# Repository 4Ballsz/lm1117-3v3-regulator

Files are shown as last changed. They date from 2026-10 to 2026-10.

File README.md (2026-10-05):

# LM1117 3.3 V Regulator Board

A 5 V → 3.3 V linear regulator board for loads up to 500 mA, on a 28 × 17 mm two-layer PCB. I did the schematic, part selection, layout and fabrication outputs in Altium Designer 26. It was my first PCB.

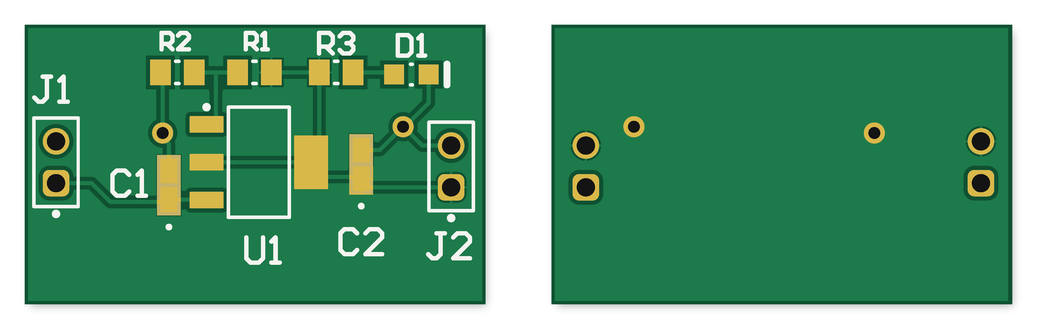
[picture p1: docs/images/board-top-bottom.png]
Top and bottom of the board, rendered from the fabrication Gerbers

<sub>Top (left) and bottom (right), rendered from the Gerber and drill files in [`fabrication/`](fabrication/).</sub>

> **Status:** design complete, DRC clean, fabrication files generated. Not yet fabricated or tested. All performance figures below are calculated, not measured.

---

## Specs

| | |
|---|---|
| Input | 5 V via J1 (2-pin 2.54 mm header) |
| Output | 3.29 V nominal, 3.19–3.41 V worst case, via J2 |
| Design load | 500 mA |
| Regulator | TI LM1117-ADJ, SOT-223 |
| Dissipation at full load | 0.85 W |
| Junction temperature | 89 °C at 25 °C ambient, 109 °C at 45 °C (limit 125 °C) |
| Board | 28 × 17 mm, 2 layers, 1 oz copper |
| Power indicator | Red LED on the 3.3 V rail, 3 mA |
| Parts | 9 components, $5.64 CAD ([BOM](bom/BOM.csv)) |

## Schematic

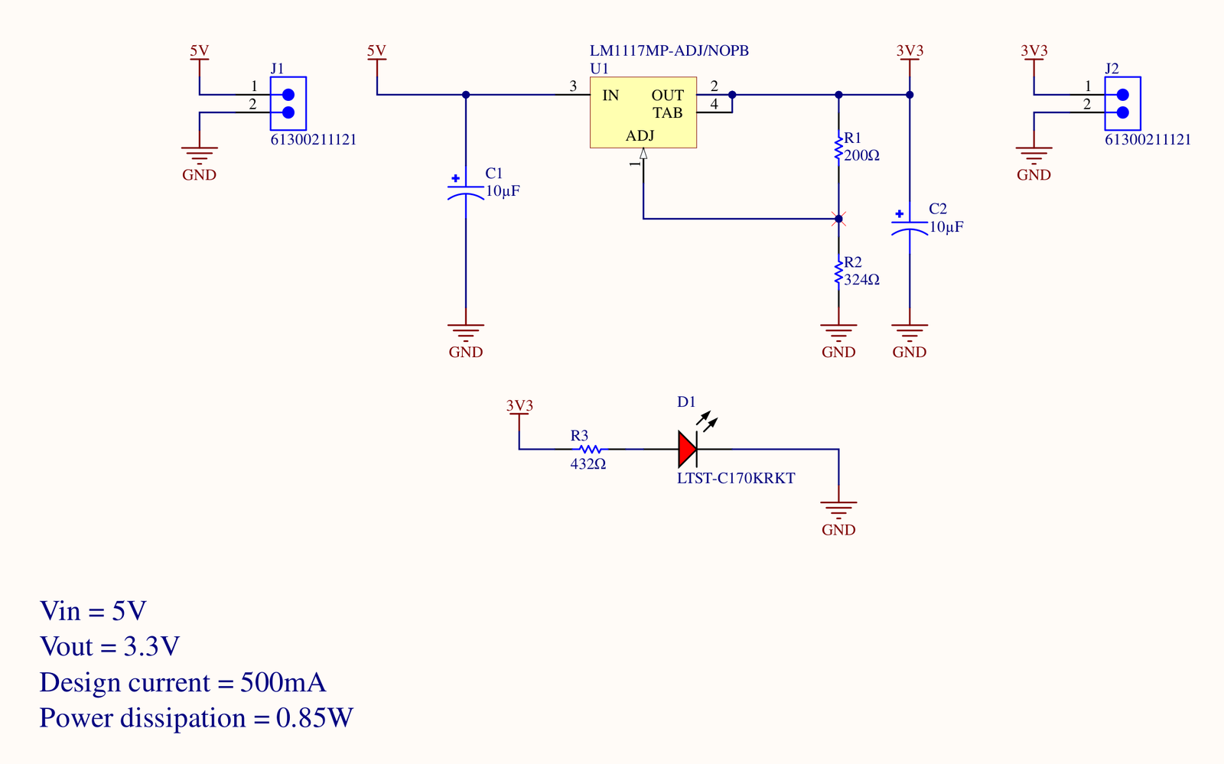
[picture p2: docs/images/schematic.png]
Schematic


- **J1** brings in 5 V and **J2** takes 3.3 V out. Pin 1 is the rail and pin 2 is ground on both. Pin 1 is the square pad.
- **R1/R2** set the output voltage through the ADJ pin.
- **C1** on the input and **C2** on the output, both tantalum.
- **D1 + R3** sit on the 3.3 V rail, so the LED shows the regulator is actually producing an output, not just that 5 V is plugged in.

Full sheet: [`docs/schematic.pdf`](docs/schematic.pdf)

---

## Key design decisions

Full working for every number is in [`docs/design-notes.md`](docs/design-notes.md).

**Output voltage: R1 = 200 Ω, R2 = 324 Ω**

    Vout = Vref × (1 + R2/R1) + Iadj × R2
         = 1.25 × (1 + 324/200) + 60 µA × 324
         = 3.275 + 0.019 = 3.294 V

- My first attempt was 1 kΩ / 1.65 kΩ. There the ADJ pin current alone added 99–198 mV (+3 % to +6 %). Dropping both by 5× cut that to 19–39 mV.
- The divider now draws 6.25 mA. That's also above the LM1117's 5 mA worst-case minimum load, so the output stays in regulation with nothing plugged into J2.
- Worst case with 1 % resistors, Vref limits and ADJ current over 0–125 °C is 3.19–3.41 V, inside a ±5 % rail (3.135–3.465 V).

**Thermal: 346 mm² copper pour on the tab**

    P  = (Vin − Vout) × I = (5 − 3.3) × 0.5 = 0.85 W
    Tj = Ta + P × θJA

- The SOT-223 tab is V_OUT, not ground (datasheet Fig. 6-1). So the heatsink pour is on the 3V3 net, not GND.
- With the bare pad (θJA = 136 °C/W) the junction would hit 141 °C at 25 °C ambient, so the pour is required.
- The built pour is 346 mm² (0.54 in²). That puts θJA at about 75 °C/W (TI Table 9-2), giving Tj = 89 °C at 25 °C and 109 °C at 45 °C.

**Output capacitor: tantalum, chosen for ESR**

- The LM1117 needs 0.3–22 Ω of ESR on the output capacitor to keep its loop stable.
- A ceramic (≈5 mΩ) or a tantalum-polymer part is below that window and could oscillate.
- Used a Kyocera AVX F921A106MPA: 10 µF, 10 V, ESR 6 Ω. The 10 V rating is 2× derating on the 5 V input, since tantalums fail short when over-voltaged.

**Trace width: 0.254 mm everywhere**

    IPC-2221 (external): I = 0.048 × ΔT^0.44 × A^0.725

- At 1 oz (1.4 mil), a 0.254 mm trace carries 0.90 A for a 10 °C rise, or rises 2.7 °C at 0.5 A.
- The minimum width for 0.5 A would be 0.11 mm.

## Layout

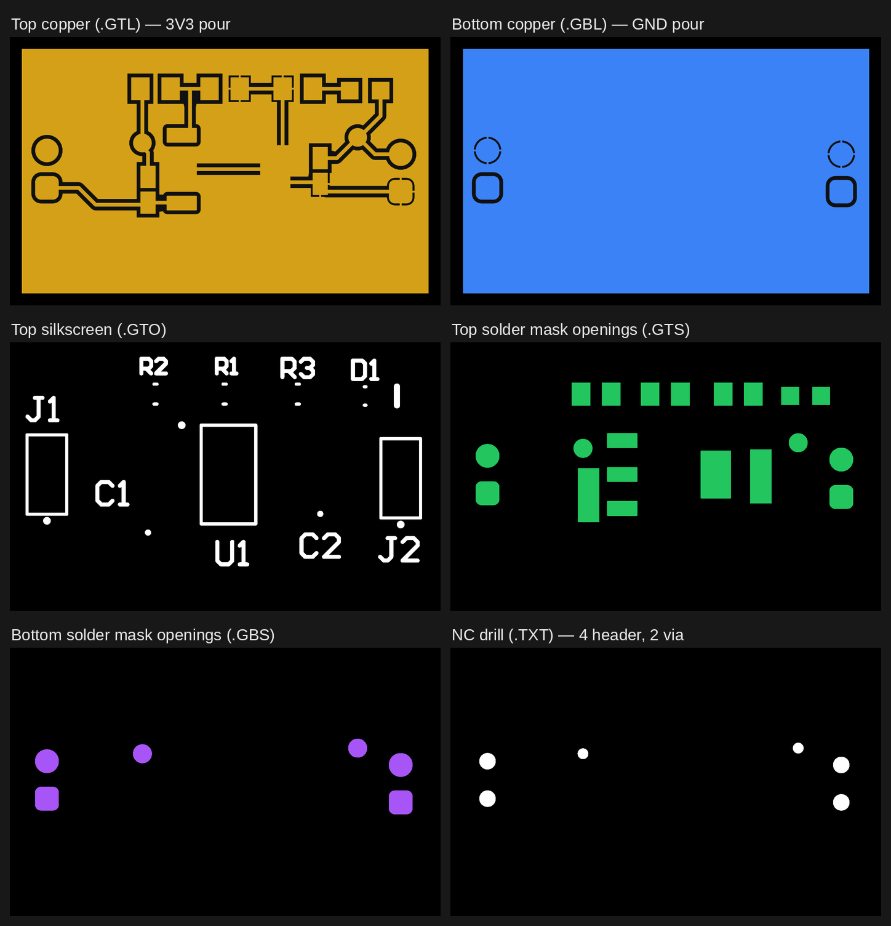
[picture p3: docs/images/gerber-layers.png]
Gerber layers


- **Top:** 3V3 pour (346 mm²) bonded to the regulator tab with a **direct connect** rule on U1. Thermal-relief spokes would choke the heat path the pour exists for. Everything else uses 4-spoke relief so it stays hand-solderable.
- **Bottom:** solid GND pour. J1/J2 ground pins are through-hole and land on it directly. The SMD ground pads on top reach it through **two 0.71 mm vias**.
- **Placement** runs input on the left to output on the right: J1 → C1 → U1 → C2 → J2. The divider and LED sit in a row along the top edge.
- **C1/C2 solder mask:** the tantalum footprint leaves only 0.24 mm between pads, under the 0.254 mm minimum mask sliver. I set +0.2 mm mask expansion on those two parts, which merges each pair of openings into one. No sliver means no violation, at the cost of no mask dam between the pads, so they need care to avoid a solder bridge.

**DRC: 0 violations, 0 warnings** ([report](docs/DRC_report.html)). The exported Gerber and drill files were also cross-checked independently: holes centred on pads, netlist, pour area, polarity. See [`docs/verification.md`](docs/verification.md).

## Bill of materials

| Ref | Part | MPN | Package | Qty | Unit (CAD) |
|---|---|---|---|---|---|
| U1 | LDO regulator, adjustable | TI LM1117MP-ADJ/NOPB | SOT-223 | 1 | 2.58 |
| C1, C2 | 10 µF 10 V tantalum, ESR 6 Ω | Kyocera AVX F921A106MPA | 0805 | 2 | 1.00 |
| R1 | 200 Ω 1 % | KOA RK73H2ATTD2000F | 0805 | 1 | 0.14 |
| R2 | 324 Ω 1 % | KOA RK73H2ATTD3240F | 0805 | 1 | 0.14 |
| R3 | 432 Ω 1 % | KOA RK73H2ATTD4320F | 0805 | 1 | 0.14 |
| D1 | Red LED | Lite-On LTST-C170KRKT | 0805 | 1 | 0.26 |
| J1, J2 | 2-pin header, 2.54 mm | Würth 61300211121 | THT | 2 | 0.19 |
| | | | | **9** | **$5.64** |

With DigiKey part numbers: [`bom/BOM.xlsx`](bom/BOM.xlsx) · [`bom/BOM.csv`](bom/BOM.csv)

## Known issues and Rev 2

- **Mechanical 1 carries a "U1" label** from the regulator footprint as well as the board outline. Use `PCB2.GM` (board profile) as the outline layer when ordering. See [`fabrication/README.md`](fabrication/README.md).
- **No pin labels on the silkscreen.** Only the square pad marks pin 1. Rev 2 should print `5V` / `GND` / `3V3` next to J1 and J2.
- **No reverse-polarity protection.** Swapping the J1 wires would reverse-bias C1. A series Schottky or P-FET would fix that at the cost of some headroom.
- **Thermal numbers come from TI's still-air test board**, not a measurement. Rev 2 would build the board and check the tab temperature at 500 mA.

## Repository layout

```
hardware/      Altium project: LM1117_Regulator.PrjPcb (open this), Sheet1.SchDoc, PCB2.PcbDoc,
               LM1117_Regulator.BomDoc (ActiveBOM), F921A106MPA/ (capacitor symbol + footprint)
fabrication/   Gerbers (RS274X, mm 4:4), NC drill, zipped fab package, fab notes
bom/           Bill of materials (.xlsx with formulas, .csv)
docs/          Schematic PDF, design notes, verification, DRC report, images
```

## Background

The requirements (5 V → 3.3 V at 500 mA, LM1117-ADJ, two layers) came from the WATonomous Humanoid electrical onboarding assignment. This repository is my own cleaned-up version of that design.

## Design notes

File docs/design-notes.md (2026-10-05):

# Design notes

Full working behind every number in the README. Datasheet references are to the TI LM1117 datasheet (SNOS412) unless stated otherwise.

---

## Datasheet values used

| What | Value | Where |
|---|---|---|
| Tab connection | **V_OUT**, not ground | LM1117 Fig. 6-1 |
| SOT-223 pins | 1 = ADJ, 2 = V_OUT, 3 = V_IN, tab = V_OUT | LM1117 Table 6-1 |
| Reference voltage | 1.238 / 1.25 / 1.262 V at 25 °C (±0.96 %) | LM1117 §7.5 |
| | 1.225 – 1.270 V over 0–125 °C, 10–800 mA | |
| ADJ pin current | 60 µA typ, 120 µA max | LM1117 §7.5 |
| Minimum load current | 1.7 mA typ, 5 mA max | LM1117 §7.5 |
| Dropout at 500 mA | 1.15 V typ, 1.25 V max over 0–125 °C | LM1117 §7.5 |
| Output capacitor | ≥ 10 µF, ESR **0.3 – 22 Ω** | LM1117 §9.2.2.1.3 |
| Junction temperature | 125 °C operating, 150 °C absolute max | LM1117 §7.3, §7.1 |
| θJA, SOT-223 | 136 °C/W bare pad → 66 °C/W at 1 in² | LM1117 Table 9-2 |
| LED forward voltage | 1.5 – 2.4 V at 20 mA, no typical given | LTST-C170KRKT datasheet |
| Capacitor ESR | 6 Ω | F921A106MPA datasheet |

---

## Divider: R1 = 200 Ω, R2 = 324 Ω

The LM1117 holds Vref = 1.25 V between OUT and ADJ, so the resistor ratio sets the output.

    Vout = Vref × (1 + R2/R1)

Rearranging for the ratio:

    R2/R1 = Vout/Vref − 1
          = 3.3/1.25 − 1
          = 1.64

Picking R1 = 200 Ω:

    R2   = 1.64 × 200        = 328 Ω   →  E96: 324 Ω
    Vout = 1.25 × (1 + 324/200) = 3.275 V
    Idiv = Vref/R1 = 1.25/200   = 6.25 mA

**ADJ pin current.** The simple equation assumes the same current flows through both resistors. The ADJ pin also pushes its own current into R2:

    Vout = Vref × (1 + R2/R1) + Iadj × R2

    60 µA  × 324 Ω = 19 mV   →  3.294 V   (−0.2 %)
    120 µA × 324 Ω = 39 mV   →  3.314 V   (+0.4 %)

**Why the values are low.**

- First attempt was 1 kΩ / 1.65 kΩ. The ADJ term was then 99–198 mV (+3 % to +6 %), worse than the resistor tolerance.
- Dividing both by 5 brought it to 19–39 mV.
- The divider current (6.25 mA) is now ~100× the ADJ current, and only 1.25 % of the 500 mA load.
- 6.25 mA also exceeds the 5 mA worst-case minimum load. With the LED's 3 mA, the regulator sees 9.3 mA even with J2 unplugged, so it stays in regulation with no load.
- 324 Ω beat 332 Ω because its rounding error goes negative and partly cancels the ADJ error.

**Power check:**

    P = I² × R
    R1: (6.25 mA)² × 200 Ω = 7.8 mW    } vs 250 mW rating
    R2: (6.25 mA)² × 324 Ω = 12.7 mW   }

---

## Tolerance

Resistor extremes come from pushing the two resistors in opposite directions:

    worst high:  R1 −1 %, R2 +1 %  →  198 Ω / 327.24 Ω  →  ratio +1.25 %
    worst low:   R1 +1 %, R2 −1 %  →  202 Ω / 320.76 Ω  →  ratio −1.22 %

So ±1 % resistors give about ±1.2 % on the output.

Stacking the reference and ADJ current at their limits as well (low end uses typical Iadj, since the datasheet gives no minimum):

| Conditions | Output range | vs 3.3 V |
|---|---|---|
| 25 °C | 3.22 – 3.39 V | −2.3 % / +2.6 % |
| 0–125 °C, 10–800 mA | 3.19 – 3.41 V | −3.4 % / +3.3 % |

A 3.3 V rail is normally ±5 %, so 3.135 – 3.465 V. **Both cases fit.** Even assuming zero ADJ current, the low end only drops to 3.17 V.

- 1 % resistors are enough; 0.1 % would buy little.
- Over the full range the reference tolerance dominates, not the resistors.
- This is a straight worst-case stack. An RSS estimate would be tighter.

---

## Thermal

A linear regulator burns the input–output difference as heat, and the same current flows in and out:

    P = (Vin − Vout) × Iload
      = (5 − 3.3) × 0.5
      = 0.85 W

Cross-check: 2.5 W in, 1.65 W out, 0.85 W left as heat.

### Efficiency

    η = Pout/Pin = (Vout × I)/(Vin × I) = Vout/Vin
      = 3.3/5 = 66 %

- The current cancels, so efficiency depends only on the voltage ratio, not on the load.
- Layout can't improve it. The only levers are a smaller input–output gap or a switching regulator.

### Junction temperature

    Tj = Ta + P × θJA

θJA depends on how much copper the tab is soldered to. From Table 9-2, SOT-223, top-side copper only:

| Copper area | θJA (°C/W) | Rise at 0.85 W | Tj at 25 °C | Tj at 45 °C |
|---|---|---|---|---|
| 0.0123 in² (bare pad) | 136 | 115.6 °C | 140.6 °C | 160.6 °C |
| 0.066 in² | 123 | 104.6 °C | 129.6 °C | 149.6 °C |
| 0.3 in² (planned) | 84 | 71.4 °C | 96.4 °C | 116.4 °C |
| **0.53 in² (as built)** | **75** | **63.8 °C** | **88.8 °C** | **108.8 °C** |

- Against the 125 °C operating limit, the bare pad and 0.066 in² both fail. The pour isn't optional.
- I planned for 0.3 in² (≈194 mm²). The pour, filling the space around the parts, came out at **346 mm² (0.54 in²)**, so the 0.53 in² row applies: 36 °C of margin at 25 °C and 16 °C at 45 °C.
- Returns flatten out: 0.0123 → 0.3 in² buys 52 °C/W, while 0.3 → 1.0 in² buys only 18 °C/W more.
- TI's numbers assume still air on their test board. A real enclosure will run hotter.

### Dropout

    headroom = Vin − Vout = 5 − 3.3 = 1.7 V
    worst-case dropout at 500 mA = 1.25 V
    margin = 0.45 V   →  regulates down to Vin ≈ 4.55 V

---

## Capacitors: both F921A106MPA

- The LM1117 uses the output capacitor's ESR to damp its feedback loop. The 0.3–22 Ω window is a stability requirement, not a parasitic to minimise.
- A ceramic sits around 5 mΩ, below the floor, and could let the loop oscillate. That can still read about 3.3 V on a multimeter.
- Tantalum-polymer parts fail the same test, so the number to check is ESR, not the word "tantalum".
- Picked 10 µF, 10 V, ESR 6 Ω, mid-window.

Voltage rating:

    rating ≥ 2 × operating voltage
    C1: 5.0 V × 2 = 10 V
    C2: 3.3 V × 2 = 6.6 V  →  10 V

2× because tantalums fail short when over-voltaged. One 10 V part covers both positions.

- The caps are ±20 %, so worst case is 8 µF against the 10 µF guideline. No ±10 % part exists in 0805 at 10 V. More capacitance only helps stability, so I accepted it.
- The optional ADJ bypass cap is left off. It only improves ripple rejection.

---

## LED: D1 + R3 = 432 Ω

Whatever the rail doesn't drop across the LED lands on the resistor:

    Vr = Vrail − Vf
    R  = Vr / Itarget

Target 3 mA. An indicator only needs to be visible.

    Vr = 3.3 − 2.0          = 1.3 V
    R  = 1.3 / 0.003        = 433.3 Ω  →  E96: 432 Ω
    I  = 1.3 / 432          = 3.01 mA
    P  = (3.01 mA)² × 432 Ω = 3.9 mW   (vs 250 mW rating)

The datasheet gives only 1.5 V min and 2.4 V max, so I used 2.0 V and checked both ends:

    Vf = 1.5 V  →  4.17 mA
    Vf = 2.4 V  →  2.08 mA

Both are well under 20 mA.

---

## Trace width

IPC-2221, external layer, 10 °C rise:

    I = k × ΔT^0.44 × A^0.725      k = 0.048, A in mil²

The stackup uses 1.4 mil copper (1 oz). For the 0.254 mm (10 mil) traces on the board:

    A = 10 × 1.4             = 14.0 mil²
    I = 0.048 × 10^0.44 × 14^0.725
      = 0.048 × 2.754 × 6.78
      = 0.90 A

Solving the other way for the design current:

    A = 6.26 mil²   →   width = 6.26 / 1.4 = 4.5 mil = 0.11 mm
    temperature rise of a 0.254 mm trace at 0.5 A = 2.7 °C

- 0.254 mm carries about 1.8× the design current.
- The 3V3 side mostly runs through the pour anyway. The 5V side (J1 → C1 → U1) is all trace, and that's where the check matters.

---

## Design rules (as built)

| Rule | Value |
|---|---|
| Clearance | 0.254 mm |
| Trace width | 0.254 mm (min = max = preferred) |
| Via | 1.27 mm diameter, 0.711 mm hole |
| Hole size | 0.025 – 2.54 mm |
| Min annular ring | 0.076 mm (actual: header 0.25 mm, via 0.28 mm) |
| Solder mask expansion | 0 mm; **+0.2 mm on C1/C2** |
| Min solder mask sliver | 0.254 mm |
| Silk to solder mask | 0.15 mm |
| Polygon connect | 4-spoke relief, 0.127 mm spokes; **direct connect on U1**; vias direct |
| Stackup | 1.4 mil Cu / 0.32 mm FR-4 / 1.4 mil Cu |

Notes on the two non-default rules:

- **Direct connect on U1.** Relief spokes would restrict exactly the heat path the pour is there for. The cost is that the tab is harder to hand-solder.
- **+0.2 mm mask on C1/C2.** The footprint's pads are 0.24 mm apart, below the 0.254 mm sliver minimum. The extra expansion makes the two openings overlap by 0.16 mm, so there's no sliver left to violate the rule. The trade-off is no mask dam between the pads, which raises bridging risk when soldering.

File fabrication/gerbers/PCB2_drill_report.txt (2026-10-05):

----------------------------------------------------------------------------------------------------------------------------------
NCDrill File Report For: PCB2.PcbDoc   10/2/2026  12:27:38 AM
----------------------------------------------------------------------------------------------------------------------------------

Layer Pair : Top Layer to Bottom Layer
ASCII RoundHoles File : PCB2.TXT

Tool       Hole Size               Hole Tolerance               Hole Type       Hole Count   Plated         Tool Travel
----------------------------------------------------------------------------------------------------------------------------------
T1      0.711mm (28mil)                                           Round             2         PTH        14.61mm (0.58inch)
T2      1.1mm (43mil)                                             Round             4         PTH        29.08mm (1.15inch)
----------------------------------------------------------------------------------------------------------------------------------
Totals                                                                              6

Total Processing Time (hh:mm:ss) : 00:00:00

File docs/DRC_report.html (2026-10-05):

Altium

# Design Rule Verification Report

Date: | | 10/2/2026
Time: | | 2:05:43 PM
Elapsed Time: | | 00:00:00
Filename: | | C:\Users\Public\Documents\Altium\Youji_Li_WATautonomous_onboarding\PCB2.PcbDoc

Warnings: | | 0
Rule Violations: | | 0

## Summary

Warnings | Count
Total | 0

Rule Violations | Count
Clearance Constraint (Gap=0.127mm) (All),(All) | 0
Clearance Constraint (Gap=0.254mm) (All),(All) | 0
Short-Circuit Constraint (Allowed=No) (All),(All) | 0
Short-Circuit Constraint (Allowed=No) (All),(All) | 0
Un-Routed Net Constraint ( (All) ) | 0
Un-Routed Net Constraint ( (All) ) | 0
Modified Polygon (Allow modified: No), (Allow shelved: No) | 0
Modified Polygon (Allow modified: No), (Allow shelved: No) | 0
Width Constraint (Min=0.254mm) (Max=0.254mm) (Preferred=0.254mm) (All) | 0
Width Constraint (Min=0.127mm) (Max=25.4mm) (Preferred=0.127mm) (All) | 0
Routing Topology Rule(Topology=Shortest) (All) | 0
Routing Topology Rule(Topology=Shortest) (All) | 0
Power Plane Connect Rule(Relief Connect )(Expansion=0.508mm) (Conductor Width=0.254mm) (Air Gap=0.254mm) (Entries=4) (All) | 0
Power Plane Connect Rule(Direct Connect )(Expansion=0.508mm) (Conductor Width=0.254mm) (Air Gap=0.254mm) (Entries=4) (InPadClass('PowerPads')) | 0
Power Plane Connect Rule(Relief Connect )(Expansion=0.3mm) (Conductor Width=0.127mm) (Air Gap=0.127mm) (Entries=4) (All) | 0
Minimum Annular Ring (Minimum=0.076mm) (All) | 0
Hole Size Constraint (Min=0.3mm) (Max=6.3mm) (All) | 0
Hole Size Constraint (Min=0.025mm) (Max=2.54mm) (All) | 0
Hole To Hole Clearance (Gap=0.254mm) (All),(All) | 0
Hole To Hole Clearance (Gap=0.25mm) (All),(All) | 0
Minimum Solder Mask Sliver (Gap=0.254mm) (All),(All) | 0
Minimum Solder Mask Sliver (Gap=0mm) (All),(All) | 0
Silk To Solder Mask (Clearance=0.15mm) (IsPad),(All) | 0
Silk to Silk (Clearance=0.254mm) (All),(All) | 0
Silk to Silk (Clearance=0mm) (All),(All) | 0
Net Antennae (Tolerance=0mm) (All) | 0
Net Antennae (Tolerance=0mm) (All) | 0
Board Clearance Constraint (Gap=0mm) (All) | 0
Height Constraint (Min=0mm) (Max=1816.048mm) (Prefered=12.7mm) (All) | 0
Height Constraint (Min=0mm) (Max=25.4mm) (Prefered=12.7mm) (All) | 0
Total | 0

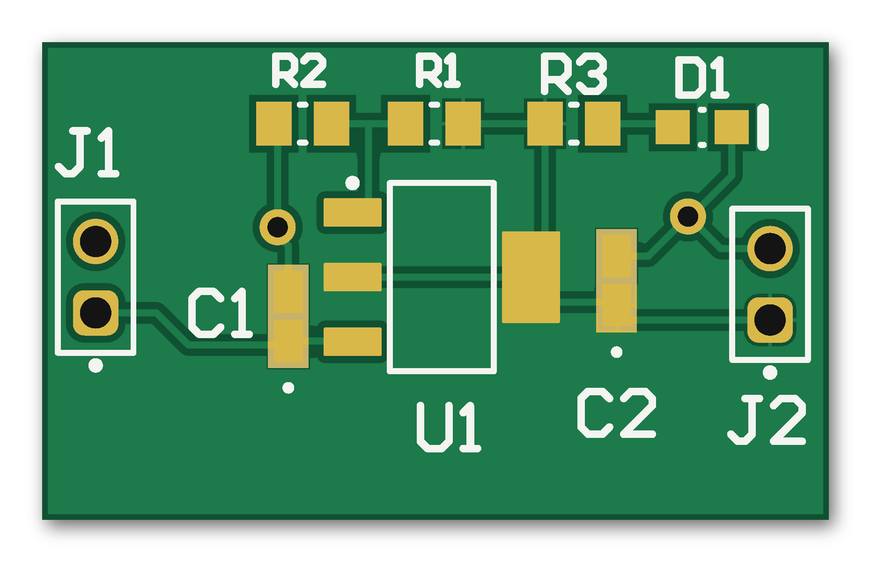
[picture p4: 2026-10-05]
docs/images/board-top.png

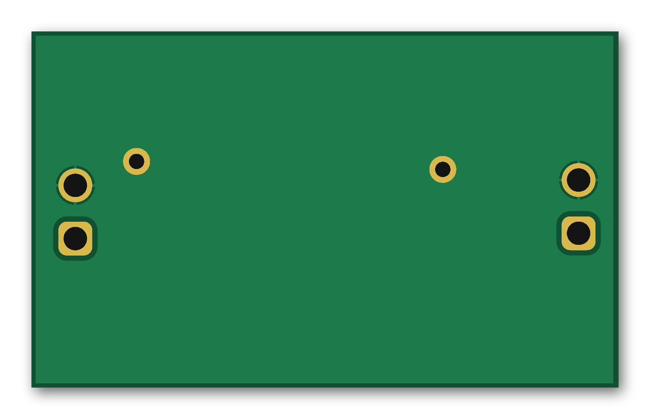
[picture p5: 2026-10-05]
docs/images/board-bottom.png

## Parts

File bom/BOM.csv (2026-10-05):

Designator | Qty | Value | Footprint | Manufacturer | MPN | Supplier | Supplier PN | Unit Price (CAD) | Ext. Price (CAD) | Description
C1, C2 | 2 | 10 µF 10 V | 0805 tantalum (CAPPM2012X120) | Kyocera AVX | F921A106MPA | DigiKey | 478-11412-1-ND | 1.00 | 2.00 | Tantalum MnO2, 10 µF ±20 %, 10 V, ESR 6 Ω, case P (0805)
D1 | 1 | Red, 631 nm | 0805 (LTST-C170KRKT_V) | Lite-On Inc. | LTST-C170KRKT | DigiKey | 160-1415-1-ND | 0.26 | 0.26 | Chip LED, red, 0805, Vf 1.5–2.4 V @ 20 mA
J1, J2 | 2 | 1×2 header | THT 1×2, 2.54 mm (61300211121) | Würth Elektronik | 61300211121 | DigiKey | 732-5315-ND | 0.19 | 0.38 | WR-PHD pin header, straight, male, 2 pos, 2.54 mm, 3 A
R1 | 1 | 200 Ω 1 % | 0805 (RESC2013X60X30ML20T20) | KOA Speer | RK73H2ATTD2000F | DigiKey | 2019-RK73H2ATTD2000FCT-ND | 0.14 | 0.14 | Thick film, 200 Ω, ±1 %, 0.25 W, 0805 — divider top (OUT–ADJ)
R2 | 1 | 324 Ω 1 % | 0805 (RESC2013X60X30ML20T20) | KOA Speer | RK73H2ATTD3240F | DigiKey | 2019-RK73H2ATTD3240FCT-ND | 0.14 | 0.14 | Thick film, 324 Ω, ±1 %, 0.25 W, 0805 — divider bottom (ADJ–GND)
R3 | 1 | 432 Ω 1 % | 0805 (RESC2013X60X30ML20T20) | KOA Speer | RK73H2ATTD4320F | DigiKey | 2019-RK73H2ATTD4320FCT-ND | 0.14 | 0.14 | Thick film, 432 Ω, ±1 %, 0.25 W, 0805 — LED current limit
U1 | 1 | LM1117-ADJ | SOT-223 (DCY0004A_M) | Texas Instruments | LM1117MP-ADJ/NOPB | DigiKey | LM1117MP-ADJ/NOPBCT-ND | 2.58 | 2.58 | LDO regulator, adjustable 1.25–13.8 V, 800 mA, SOT-223; tab = V_OUT
TOTAL | 9 |  |  |  |  |  |  |  | 5.64

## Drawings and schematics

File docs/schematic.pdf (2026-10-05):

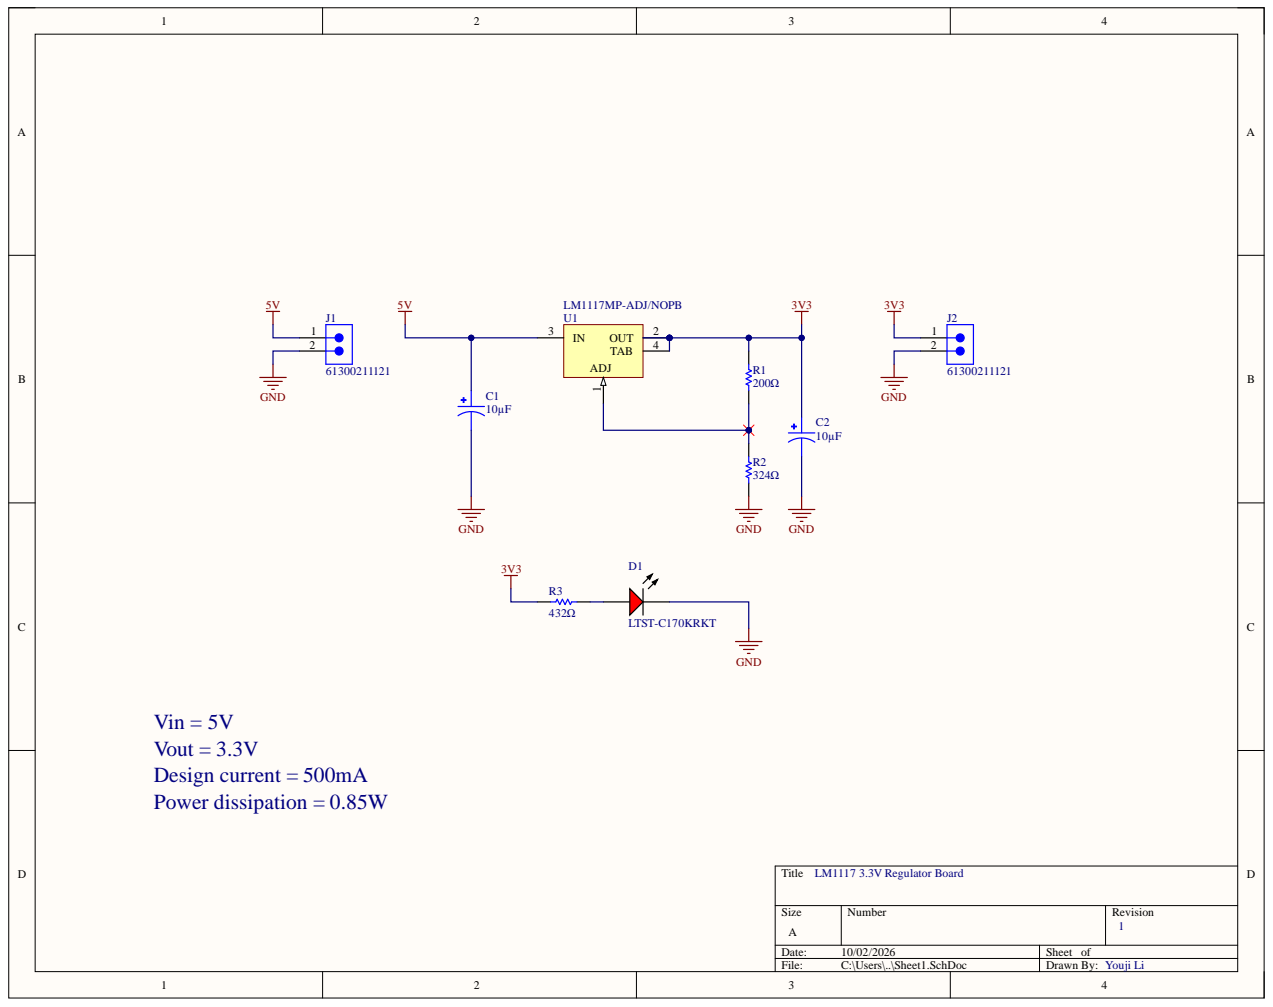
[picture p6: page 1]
Title; Size; Revisio; Date:; Sheet o; File:; C:\Users\..\Sheet1.SchDo; Drawn B; OUT; TAB; ADJ; 7MP-ADJ/NOPB; D1 LTST; 0KRKT; GND; Vin = 5V Vout = 3.3V; V Reg; ulato; oar; uji Li 1

Design current = 500mA Power dissipation = 0.85W

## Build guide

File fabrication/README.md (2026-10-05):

# Fabrication

`LM1117_Regulator_Rev1_gerbers.zip` contains everything a fab needs. The same files are unzipped in [`gerbers/`](gerbers/).

| File | Layer |
|---|---|
| `PCB2.GTL` | Top copper (3V3 pour) |
| `PCB2.GBL` | Bottom copper (GND pour) |
| `PCB2.GTO` | Top silkscreen |
| `PCB2.GTS` | Top solder mask |
| `PCB2.GBS` | Bottom solder mask |
| `PCB2.GM` | **Board outline — use this one** |
| `PCB2.GM1` | Mechanical 1 (outline plus a "U1" assembly label) |
| `PCB2.TXT` | NC drill, Excellon, plated |

Format: RS274X, millimetres, 4:4, absolute. Drill: metric, 4:4. `PCB2_drill_report.txt` lists the tools.

## Ordering

| Parameter | Value |
|---|---|
| Layers | 2 |
| Size | 28 × 17 mm |
| Thickness | **1.6 mm** |
| Copper | 1 oz |
| Min trace / space | 0.254 / 0.254 mm |
| Min hole | 0.71 mm |
| Surface finish | HASL or ENIG |
| Solder mask | Any colour |

- **Thickness:** the Altium stackup is the 0.41 mm default. Order 1.6 mm so the headers have a rigid board to plug into. Nothing in the Gerbers depends on thickness.
- **Outline layer:** `PCB2.GM1` also carries a small "U1" label inside the board. Some fabs read Mechanical 1 as the routing path. Point them at `PCB2.GM`, or delete `PCB2.GM1` from the zip if their uploader complains.

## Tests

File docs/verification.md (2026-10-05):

# Output verification

DRC confirms the board matches its rules inside Altium. These checks were run on the **exported fabrication files** and the PCB database, which is what a fab actually receives.

## Design rule check

- **0 violations, 0 warnings** in Altium DRC ([`DRC_report.html`](DRC_report.html)).

## Gerber and drill format

| Check | Result |
|---|---|
| Gerber format | RS274X (extended), apertures embedded (`%ADD…%`) |
| Units / precision | millimetres (`%MOMM*%`), 4:4 (`%FSLAX44Y44*%`), absolute |
| Layers | GTL, GBL, GTO, GTS, GBS, GM (board profile), GM1 (mechanical 1) |
| Drill file | Excellon, `METRIC`, `FILE_FORMAT=4:4`, plated |
| Board outline | 28.00 × 17.00 mm |

## Drill-to-pad alignment

Every drill hit was matched to the nearest pad flash on both copper layers:

| Hole | Diameter | Offset from pad centre (top / bottom) |
|---|---|---|
| J1 pin 1 | 1.10 mm | 0.0 / 0.0 µm |
| J1 pin 2 | 1.10 mm | 0.0 / 0.0 µm |
| J2 pin 1 | 1.10 mm | 0.0 / 0.0 µm |
| J2 pin 2 | 1.10 mm | 0.0 / 0.0 µm |
| GND via (left) | 0.71 mm | 0.0 / 0.0 µm |
| GND via (right) | 0.71 mm | 0.0 / 0.0 µm |

The Gerbers and drill file share the same origin.

## Netlist (from the PCB)

| Net | Pads |
|---|---|
| 5V | J1.1, U1.3 (V_IN), C1.+ |
| 3V3 | U1.2 (V_OUT), U1.4 (tab), C2.+, R1.2, R3.2, J2.1 |
| ADJ | U1.1, R1.1, R2.2 |
| LED | R3.1, D1.1 (anode) |
| GND | J1.2, J2.2, C1.−, C2.−, R2.1, D1.2 (cathode), 2 vias |

Matches the schematic pin for pin. R1 sits between OUT and ADJ, and R2 between ADJ and GND.

## Pours and copper

- **Top pour on 3V3, bottom pour on GND.** The opposite would short the output, since the tab is V_OUT.
- **3V3 copper connected to the U1 tab: 382 mm²**, including 3V3 pads and traces. That agrees with Altium's 346 mm² for the polygon alone.
- **No floating copper.** The top layer has 7 copper islands, and each belongs to a net with pads.
- **All three top-side GND islands reach the bottom plane:** one through J1.2, one through J2.2 plus a via, one through the left via.

## Polarity

- **C1, C2:** + pad on the positive rail; silk dot on the + side.
- **D1:** symbol is anode→cathode on pins 1→2; pin 2 is on GND and carries the silkscreen cathode bar.
- **J1, J2:** pin 1 (the rail) is the square pad, marked with a silk dot.

## Library links

Each resistor links to its own workspace component, so Altium's BOM keeps them apart:

| Ref | Component | MPN |
|---|---|---|
| R1 | CMP-009-00178-1 | RK73H2ATTD2000F (200 Ω) |
| R2 | CMP-009-00177-1 | RK73H2ATTD3240F (324 Ω) |
| R3 | CMP-009-00179-1 | RK73H2ATTD4320F (432 Ω) |

R2 originally shared R1's component, so Altium's BOM listed it as 200 Ω. I gave it its own component and pushed the change to the PCB with an ECO. That was a link-only change: every pad, track, via and pour is identical before and after, so the Gerbers didn't need regenerating. DRC re-run afterwards: 0 violations.

## Known discrepancies

- `PCB2.GM1` (Mechanical 1) contains a "U1" assembly label as well as the outline. Use `PCB2.GM` as the outline layer.
